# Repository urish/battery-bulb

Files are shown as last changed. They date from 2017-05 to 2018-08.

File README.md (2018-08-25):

# battery-bulb

Battery Powered Magic Blue Bulb - Charging + Power Supply module

Learn more about it in my blog post - [How To Make Your Very Own Wireless, Extra-Magic Smart Bulb](https://medium.com/@urish/how-to-make-your-very-own-wireless-extra-magic-smart-bulb-bb40b4e3a726).

Assembled PCB

## Bill of Materials

| Name | Quantity | Unit Price | Link | Comment |
|---|---|---|---|---|
| 12V Step-Up Voltage Regulator | 1 | $3.95 | [Pololu](https://www.pololu.com/product/2117) | |
| MicroUSB Connector | 1 | $1.50 | [SparkFun](https://www.sparkfun.com/products/8533) |  |
| SMD Right Angle Switch | 1 | $0.95 | [SparkFun](https://www.sparkfun.com/products/10860) |  |
| 2-Pin JST Connector | 1 | $0.95 | [SparkFun](https://www.sparkfun.com/products/9914) | LiPo Battery Connector |
| MCP73831T | 1 | $0.15 | [AliExpress](https://www.aliexpress.com/item/10PCS-MCP73831T-2ACI-OT-SOT23-5-MCP73831T-2ACI-SOT-MCP73831T-MCP73831-SMD-free-shipping/32714249253.html) | LiPo Charging Chip  |
| RT9013-33GB | 1 | $0.19 | [AliExpress](https://www.aliexpress.com/item/RT9013-33GB-RT9013-33PB-3-3V-SOT23-5-imports-Original-New-NFTXKJ/32467674180.html) | 3.3V Voltage Regulator |
| 0603 4.7kΩ Resistor | 1 | $0.01 | - | R3 |
| 0603 10kΩ Resistor | 1 | $0.01 | - |  R2 |
| 0603 LED | 1 | $0.01 | -  | Charging indicator |
| 0603 4.7uF Capacitor | 2 | $0.01 | - | C1, C2

In addition, you will also need a small LiPo battery - a [100mAH](https://www.adafruit.com/product/1570) battery should do the trick, and obviously, [the bulb itself](https://www.gearbest.com/smart-light-bulb/pp_230349.html).

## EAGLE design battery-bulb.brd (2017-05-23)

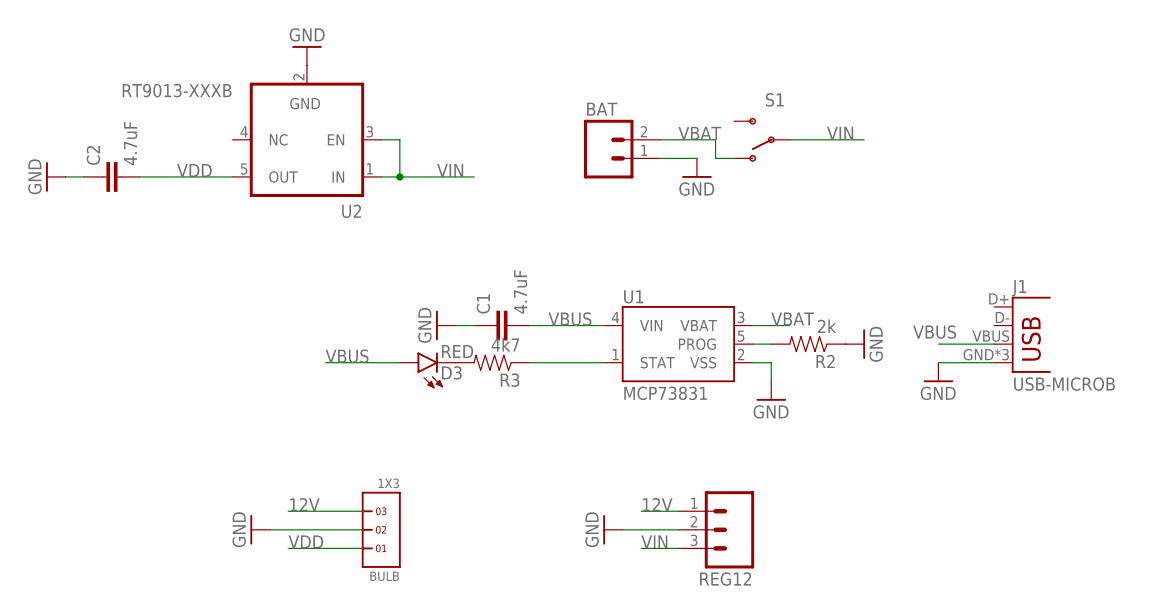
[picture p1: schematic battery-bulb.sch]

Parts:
BAT: M02JST-PTH-2; JST-2-PTH
BULB: 1X3
C1, C2: 4.7uF; 0603-CAP
D3: RED; LED-0603
J1: USB-MICROB
R2: 2k; 0603-RES
R3: 4k7; 0603-RES
REG12: M03LOCK; 1X03_LOCK
S1: SWITCH-SPDT-SMD-A; SWITCH-SPST-SMD-A
U1: MCP73831; SOT23-5
U2: RT9013-XXXB; SOT23-5

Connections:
12V: BULB.3, REG12.1
GND: BAT.1, BULB.2, C1.1, C2.1, J1.GND, J1.MT1 (GND), J1.MT2 (GND), R2.1, REG12.2, U1.2 (VSS), U2.2 (GND)
unnamed: R2.2, U1.5 (PROG)
unnamed: R3.1, U1.1 (STAT)
unnamed: D3.C, R3.2
VBAT: BAT.2, S1.1 (O), U1.3 (VBAT)
VBUS: C1.2, D3.A, J1.VBUS, U1.4 (VIN)
VDD: BULB.1, C2.2, U2.5 (OUT)
VIN: REG12.3, S1.2, U2.1 (IN), U2.3 (EN)

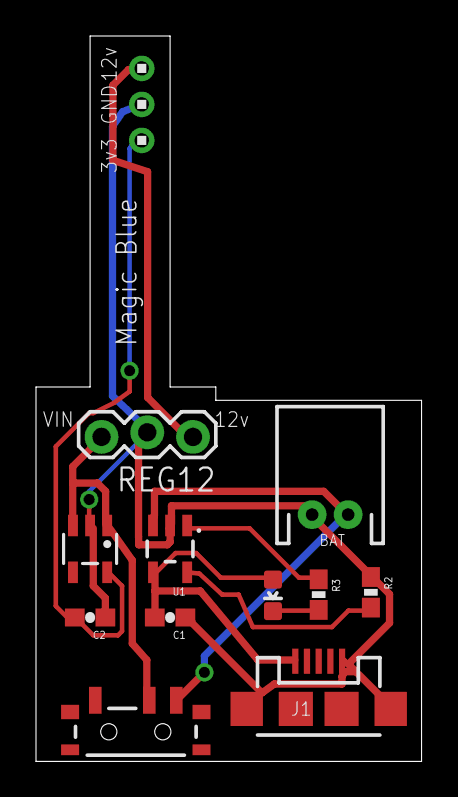
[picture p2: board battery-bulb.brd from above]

Board: 2 copper layers, 21.4 x 40.3 mm, 12 parts (0 on the bottom side), 9 nets.

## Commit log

2017-05-23 board revision 2
    extend the board with direct connection to the bulb's logic board
    [battery-bulb.brd, battery-bulb.sch]
2018-08-25 docs: update BOM
    add 12V step-up, and link to battery / bulb

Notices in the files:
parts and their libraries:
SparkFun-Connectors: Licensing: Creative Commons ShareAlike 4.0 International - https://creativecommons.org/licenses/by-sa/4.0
